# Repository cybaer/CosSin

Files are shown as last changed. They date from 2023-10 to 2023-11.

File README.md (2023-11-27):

#CosSin 

a turntable power supply (TTPSU)

* suitable for Thorens TD14x/TD16x with 16V motors
* supplies a perfectly sinusoidal voltage
* electronic switching between 33 1/3 and 45 rpm
* fine adjustment for speed and phase position
* smooth start/brake and transition to another speed
* automatic switch-off after 25 or 15 minutes

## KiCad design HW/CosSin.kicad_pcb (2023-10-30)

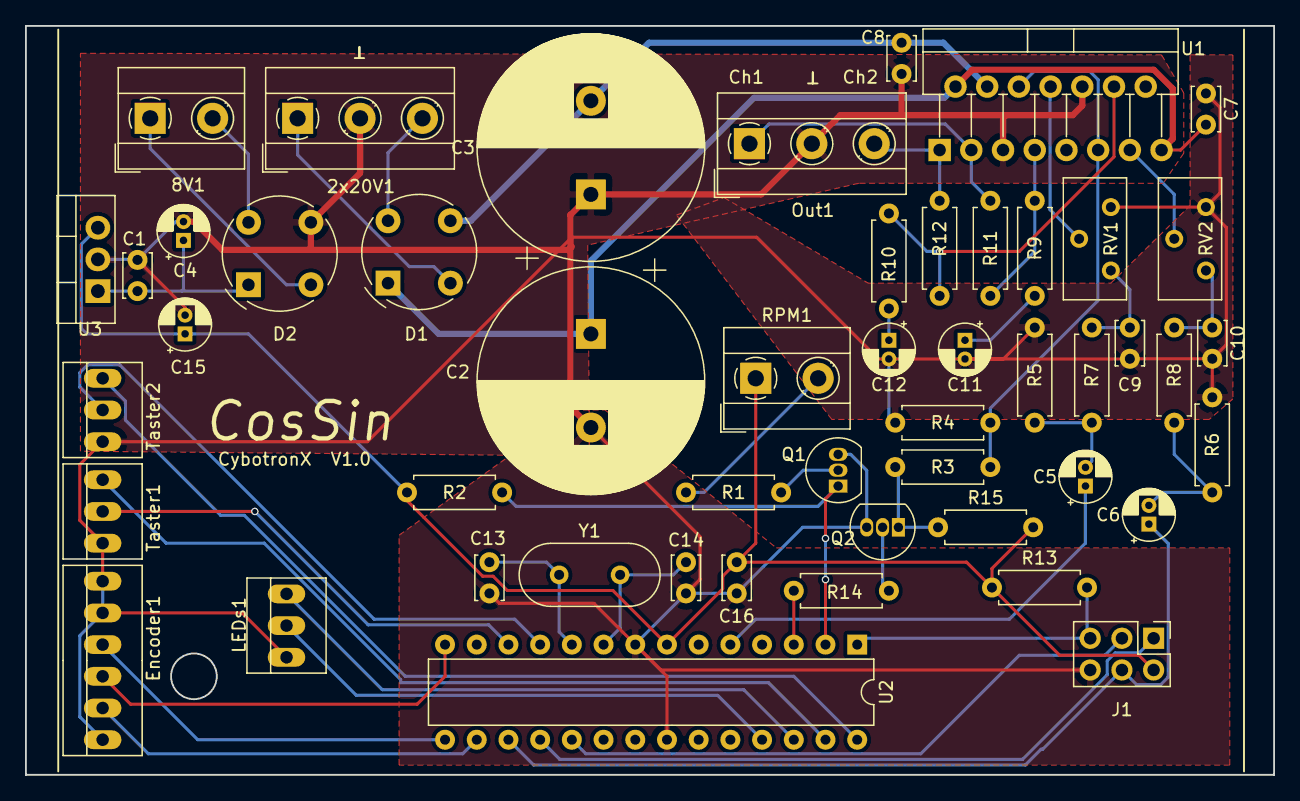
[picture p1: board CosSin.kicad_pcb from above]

Board: 2 copper layers, 100.0 x 60.0 mm, 50 parts (0 on the bottom side), 44 nets.

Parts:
2x20V1: Screw_Terminal_01x03; TerminalBlock_MetzConnect_Type055_RT01503HDWU_1x03_P5.00mm_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
8V1: Screw_Terminal_01x02; TerminalBlock_MetzConnect_Type055_RT01502HDWU_1x02_P5.00mm_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
C1, C5, C6, C11, C12, C15: 10µ; CP_Radial_D4.0mm_P1.50mm
C2, C3: 2200µ/50V; CP_Radial_D18.0mm_P7.50mm
C4, C7, C8, C9, C10, C16: 100n; C_Disc_D3.4mm_W2.1mm_P2.50mm
C13, C14: 22p; C_Disc_D3.4mm_W2.1mm_P2.50mm
D1, D2: D_Bridge_+A-A; Diode_Bridge_Round_D9.0mm
Encoder1: Conn_01x06; PINHEAD1-6
J1: AVR-ISP-6; PinHeader_2x03_P2.54mm_Vertical
LEDs1: Conn_01x03; PINHEAD1-3
Out1: Screw_Terminal_01x03; TerminalBlock_MetzConnect_Type055_RT01503HDWU_1x03_P5.00mm_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
Q1, Q2: BC547; TO-92_Inline
R1, R4, R5, R6, R14: 100K; R_Axial_DIN0207_L6.3mm_D2.5mm_P7.62mm_Horizontal
R2, R7, R8, R13, R15: 10K; R_Axial_DIN0207_L6.3mm_D2.5mm_P7.62mm_Horizontal
R3, R9, R10: 1K; R_Axial_DIN0207_L6.3mm_D2.5mm_P7.62mm_Horizontal
R11, R12: 22K; R_Axial_DIN0207_L6.3mm_D2.5mm_P7.62mm_Horizontal
RPM1: Screw_Terminal_01x02; TerminalBlock_MetzConnect_Type055_RT01502HDWU_1x02_P5.00mm_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
RV1, RV2: 100K; Potentiometer_Bourns_3296Y_Vertical
Taster1, Taster2: Conn_01x03; PINHEAD1-3
U1: LM1876; TO-220-15_P2.54x2.54mm_StaggerOdd_Lead4.58mm_Vertical
U2: ATmega328P-PU; DIP-28_W7.62mm
U3: LM7805_TO220; TO-220-3_Vertical
Y1: Crystal; Crystal_HC49-U_Vertical

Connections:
+5V: C15.1, C16.1, J1.2, R2.2, R13.1, R15.2, RPM1.1, U2.7, U3.3
DDS2: C5.1, U2.5
ENC_A: Encoder1.2, U2.16
ENC_B: Encoder1.3, U2.14
ENC_S: Encoder1.4, U2.15
GND: 2x20V1.2, C1.2, C2.2, C3.1, C4.2, C7.2, C8.1, C9.2, C10.2, C11.2, C12.2, C13.2, C14.2, C15.2, C16.2, D2.3, Encoder1.1, Encoder1.5, Encoder1.6, J1.6, LEDs1.1, Out1.2, Q1.3, Q2.3, R4.2, R5.2, R6.2, RV1.3, RV2.3, Taster1.1, Taster2.1, U1.5, U1.10, U2.8, U2.22, U3.2
LED_1: Taster1.3, U2.27
LED_2: Taster2.3, U2.28
LED_3: LEDs1.3, U2.26
LED_4: LEDs1.2, U2.25
MISO: J1.1, U2.18
MOSI: C6.1, J1.4, U2.17
Mute: R3.1, R4.1, U1.6, U1.11
Mute_: R14.2, U2.3
unnamed: 2x20V1.1, D1.2
unnamed: 2x20V1.3, D1.4
unnamed: 8V1.1, D2.2
unnamed: 8V1.2, D2.4
unnamed: C1.1, C4.1, D2.1, U3.1
unnamed: C5.2, R5.1, R7.2
unnamed: C6.2, R6.1, R8.2
unnamed: C9.1, R7.1, RV1.1
unnamed: C10.1, R8.1, RV2.1
unnamed: C11.1, R9.2
unnamed: C12.1, R10.2
unnamed: C13.1, U2.10, Y1.1
unnamed: C14.1, U2.9, Y1.2
unnamed: Out1.1, R11.1, U1.3
unnamed: Out1.3, R12.1, U1.1
unnamed: Q1.2, R1.1
unnamed: Q2.1, R3.2, R15.1
unnamed: Q2.2, R14.1
unnamed: R1.2, RPM1.2
unnamed: R10.1, R12.2, U1.12
unnamed: R9.1, R11.2, U1.7
unnamed: RV1.2, U1.8
unnamed: RV2.2, U1.13
RPM: Q1.1, R2.1, U2.2
RST: J1.5, R13.2, U2.1
SCK: J1.3, U2.19
Tast_1: Taster1.2, U2.12
Tast_2: Taster2.2, U2.11
VCC: C2.1, C7.1, D1.1, U1.2, U1.15
VEE: C3.2, C8.2, D1.3, U1.4

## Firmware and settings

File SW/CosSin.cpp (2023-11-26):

/*
 * CosSin.cpp
 *
 *  Created on: 10.01.2023
 *      Author: cybaer
 *
 * This program is free software: you can redistribute it and/or modify
 * it under the terms of the GNU General Public License as published by
 * the Free Software Foundation, either version 3 of the License, or
 * (at your option) any later version.
 * This program is distributed in the hope that it will be useful,
 * but WITHOUT ANY WARRANTY; without even the implied warranty of
 * MERCHANTABILITY or FITNESS FOR A PARTICULAR PURPOSE.  See the
 * GNU General Public License for more details.
 * You should have received a copy of the GNU General Public License
 * along with this program.  If not, see <http://www.gnu.org/licenses/>.
 */

#include <avr/io.h>
#include <avr/interrupt.h>

#include "avrlib/base.h"
#include "avrlib/time.h"
#include "avrlib/gpio.h"
#include "avrlib/adc.h"

#include "generator.h"
#include "HardwareConfig.h"
#include "ui.h"

using namespace avrlib;

// __Compiler Bug__
int __cxa_guard_acquire(__guard *g) {return !*(char *)(g);};
void __cxa_guard_release (__guard *g) {*(char *)g = 1;};
void __cxa_guard_abort (__guard *) {};
void __cxa_pure_virtual() {};

volatile uint32_t offset = 0;

typedef Gpio<PortB, 3> PIN_PWM_TIMER2A;
//const uint8_t PIN_PWM_TIMER2A = 11; // PWM output OC2A
typedef Gpio<PortD, 3> PIN_PWM_TIMER2B;
//const uint8_t PIN_PWM_TIMER2B = 3;  // PWM output OC2B

volatile uint8_t count = 0;
volatile bool poll = false; 

Generator generator;
Ui ui; 

/* Timer1 interrupt calculates the pointer, gets the value
   for the PWM from the table and outputs it */
ISR(TIMER1_COMPA_vect)
{  
  //Led_4::High(); 
  generator.calcNewPhase();
  OCR2A = generator.getValueA();
  OCR2B = generator.getValueB();

  // ca. 1KHz
  if((count++ & 0x1f) == 0x10) poll = true;
  //Led_4::Low();
}

int main(void)
{
  PIN_PWM_TIMER2A::set_mode(DIGITAL_OUTPUT); 
  PIN_PWM_TIMER2B::set_mode(DIGITAL_OUTPUT); 
  
  cli();         // stop interrupts
  /* Set Timer2 register to FastPWM */
  TCCR2A = 0xA3;
  TCCR2B = 0x01; // no prescaling (f_PWM = 20MHz/256 = 78,125kHz)
  /* Set Timer1 for Timer interrupt */
  TCCR1A = 0;  
  TCCR1B = 0x0A; // turn on CTC mode prescaler = 2
  OCR1A = 68;    // f = 2,5MHz / (OCCR1A + 1) = 36231Hz
  TIMSK1 = 0x02; // enable timer compare interrupt
  sei();         //allow interrupts

  initHW();

  _delay_ms(100);

  while(1)
  {
    if(poll)
    {
      poll = false;
      ui.doEvents();
    }                      
  }
}

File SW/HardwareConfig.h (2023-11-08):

#ifndef HARDWARECONFIG_H_
#define HARDWARECONFIG_H_

#include <avrlib/base.h>
#include <avrlib/gpio.h>
#include <avrlib/devices/rotary_encoder.h>

// __Compiler Bug__
__extension__ typedef int __guard __attribute__((mode (__DI__)));

extern "C" int __cxa_guard_acquire(__guard *);
extern "C" void __cxa_guard_release (__guard *);
extern "C" void __cxa_guard_abort (__guard *);
extern "C" void __cxa_pure_virtual();

using namespace avrlib;

typedef Inverter<Gpio<PortD, 1> > Mute;

typedef DebouncedSwitch< Gpio<PortD, 5> > Button_2;
typedef DebouncedSwitch< Gpio<PortD, 6> > Button_1;

typedef Gpio<PortB, 2> Encoder_A;
typedef Gpio<PortB, 0> Encoder_B;
typedef Gpio<PortB, 1> Encoder_S;
typedef RotaryEncoder<Encoder_A, Encoder_B, Encoder_S> Encoder;

typedef Gpio<PortC, 4> Led_1;
typedef Gpio<PortC, 5> Led_2;
typedef Gpio<PortC, 3> Led_3;
typedef Gpio<PortC, 2> Led_4;

inline void initOutputs()
{
  Mute::set_mode(DIGITAL_OUTPUT);
  Mute::High();
  Led_1::set_mode(DIGITAL_OUTPUT);
  Led_1::Low();
  Led_2::set_mode(DIGITAL_OUTPUT);
  Led_2::Low();
  Led_3::set_mode(DIGITAL_OUTPUT);
  Led_3::Low();
  Led_4::set_mode(DIGITAL_OUTPUT);
  Led_4::Low();
}

inline void initHW()
{
  initOutputs();

  Button_1::Init();
  Button_2::Init();
  Encoder::Init();
}

#endif

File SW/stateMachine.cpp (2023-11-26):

#include "HardwareConfig.h"
#include "stateMachine.h"
#include "ui.h"

void InitState::onExit(Ui& context) const
{
  context.readEEPROMData();
  context.readEEPROMStopp();
  context.initGenerator();
  Led_1::Low();
  Led_2::Low();
}

void OffState::onEntry(Ui& context) const
{
  context.setRPM0();
  Led_1::Low();
  Led_2::Low();
}
void OffState::onPush33(Ui& context) const
{
  context.setState(Run33State::getInstance());
}
void OffState::onPush45(Ui& context) const
{
  context.setState(Run45State::getInstance());
}
void OffState::onPushEncoder(Ui& context) const
{
  context.setState(EditStopState::getInstance());
}

void RunState::onPushEncoder(Ui& context) const
{
  context.setState(ChangeFreqState::getInstance());
}
void RunState::onStopCounter(Ui& context) const
{
  context.setState(OffState::getInstance());
}

void Run33State::onEntry(Ui& context) const
{
  Mute::Low();
  context.setRPM33();
  Led_2::Low();
  Led_1::High();
  
}
void Run33State::onPush33(Ui& context) const
{
  context.setState(OffState::getInstance());
}
void Run33State::onPush45(Ui& context) const
{
  context.setState(Run45State::getInstance());
}

void Run45State::onEntry(Ui& context) const
{
  context.setRPM45();
  Led_1::Low();
  Led_2::High();
  Mute::Low();
}
void Run45State::onPush33(Ui& context) const
{
  context.setState(Run33State::getInstance());
}
void Run45State::onPush45(Ui& context) const
{
  context.setState(OffState::getInstance());
}

void ChangeFreqState::onEntry(Ui& context) const
{
  Led_3::High();
}
void ChangeFreqState::onExit(Ui& context) const
{
  Led_3::Low();
}
void ChangeFreqState::onPushEncoder(Ui& context) const
{
  context.setState(ChangePhaseState::getInstance());
}
void ChangeFreqState::onIncrement(Ui& context, int8_t incr) const
{
  context.incrRPM(incr);
}

void ChangePhaseState::onEntry(Ui& context) const
{
  Led_4::High();
}
void ChangePhaseState::onExit(Ui& context) const
{
  context.writeEEPROMData();
  Led_4::Low();
}
void ChangePhaseState::onPushEncoder(Ui& context) const
{
  if(context.isSetRPM33()) context.setState(Run33State::getInstance());
  else if(context.isSetRPM45()) context.setState(Run45State::getInstance());
  else context.setState(OffState::getInstance());
}
void ChangePhaseState::onIncrement(Ui& context, int8_t incr) const
{
  context.incrPhase(incr);
}

void EditStopState::onEntry(Ui& context) const
{
  Led_1::High();
  Led_2::set_value(context.getAutoStop());
}
void EditStopState::onExit(Ui& context) const
{
  context.writeEEPROMStopp();
  Led_1::Low();
  Led_2::Low();
}
void EditStopState::onPushEncoder(Ui& context) const
{
  context.setState(OffState::getInstance());
}
void EditStopState::onIncrement(Ui& context, int8_t incr) const
{
  Led_2::set_value(context.toggleAutoStop());
}
 

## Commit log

2023-02-16 new repo
    [CosSin.kicad_pcb, CosSin.sch]
2023-02-17 switch between 33 and 45 RPM possible
2023-10-30 with SmartGenerator for smooth startup
    [CosSin.kicad_pcb]
2023-11-21 start problems without programmer cleared, beautifying
    [CosSin.cpp, stateMachine.cpp]
2023-11-26 Auto stop switchable some beautifying
